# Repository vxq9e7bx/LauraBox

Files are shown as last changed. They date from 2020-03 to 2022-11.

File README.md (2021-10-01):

# LauraBox
A children's juke box controlled by RFID tags, based on an ESP32.

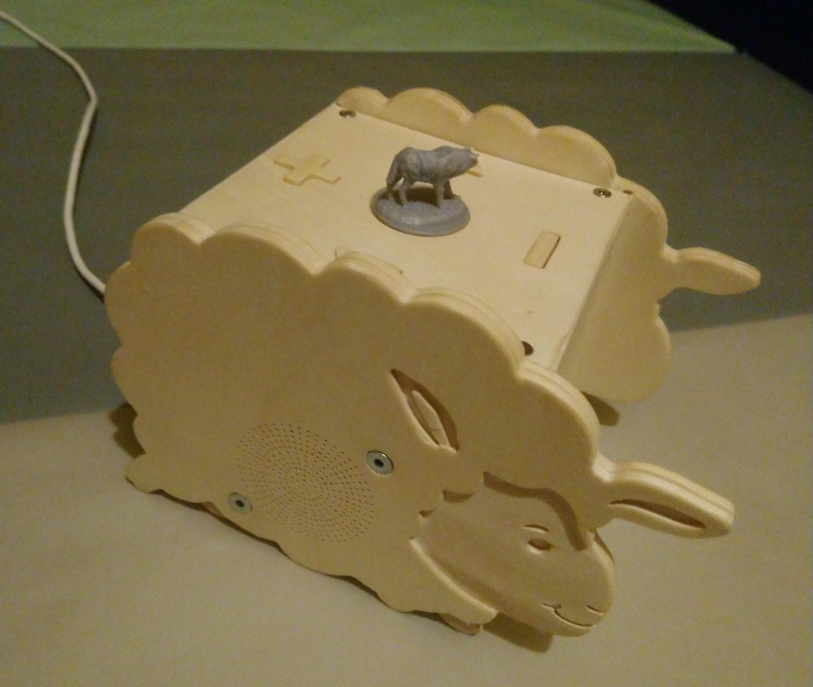
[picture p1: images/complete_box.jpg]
The ready box


## Features:
* Playback of user-defined MP3 playlists
* Playlist selected though RFID tag. Cheap RFID stickers can be placed on any 3D printed model.
* Battery powered, can play while charging
* Four buttons: volume +/-, next/previous track
* Intuitive pause functionality by removing the RFID tag and putting it back on to resume (no limit in pause time, no impact on battery life)
* WiFi download of new MP3s and playlists
* Firmware upgrade via WiFi
* Long standby time (several month)
* Long play time (many hours, if not days)
* Toddler proof :-)

## Main components
* EPS32 microcontroller
* MFRC522 RFID board
* PCM5102 I2S stereo audio DAC
* PAM8403 stereo amplifier
* Pair of wideband speakers
* 3.6V Li-ion battery with USB charge controller from a USB power bank (2x 18650-type cells with 2500 mAh)
* SD card to store MP3 files and playlists

## Why use the ESP32?

At first I was considering building the box based on a Raspberry Pi. I had an old first generation Pi lying around unused, so I though it would be a good way of using it. I was immediately disappointed by its sound quality. Although this is significantly better on newer models, I learned another lession: The power consumption of a Raspberry Pi is very high, and it takes a long time to boot. Keeping it always running to wait for an RFID card to be detected is out of the question, since I wanted it to run from battery. Adding a small microcontroller (I though of some ATMega) to switch on the Pi only when a card is detected would result in long wait times until the music starts playing. Also the power consumption while playing would be still quite high. A Raspberry Pi typically uses 300 to 500 mA, while an ESP32 just takes a few mA when WiFi is disabled. After short investigation I found the ESP32-audioI2S Arduino library. This makes playback of audio using an ESP32 super easy. Thanks to the ultra low power co-processor of the ESP32 it is possible to cut down the power consumption in sleep mode to around 0.5mA-1.0mA on average (incl. periodic wakeups and RFID reads), which gives you plenty of standby time on battery.

## Power supply

For power supply I have used an old USB power bank which I no longer needed. It has two 18650-typed cells with each 2500 mAh and a USB charge controller with an integrated boost converted to generate 5V from the ~3.6 V battery voltage (the cells are in parallel). The 5V USB voltage is not usable to power a very low power device, since the boost converter switches off if too little current is drawn. Since the electronics anyways runs on 3.3 V, the battery voltage is used without the boost converter directly. Since the voltage can be as high as 4 V or even higher when the battery is fully chaged, and the ESP32 has a maximum voltage of 3.6 V, a voltage regulator is required. I have decided for a MaxLinear XRP6272, since it has a very low quiescent current, a quite low dropout voltage and is able to provide a high enough current so that WiFi will work without problems.

The PCM5102 has unfortunately a relatively high quiescent current, hence I decided to use two XRP6272: one for the ESP32, the MRF522 and the SD card, the second formt the PCM5102. The first regulator is permanently enabled, since the ESP32 needs permanent power, and both the SD card and the MRF522 can be powered down to a sufficiently low quiescent current. Only the second regulator is controlled by software.

The PAM8403 is directly connected to the battery voltage, since it is favourable to power it with the highest possible voltage (up to 5V). I have experimented with using the 5V USB power as a supply, but it draws too little current to switch it on. Luckily, the power down mode of the PAM8403 is also sufficiently low, so no extra switch is required here.

It is a bit difficult to measure the power consumption in standby mode precisely, because it switches between deep-sleep modes and very short bursts of RFID-activity (with only the ULP processor working in the ESP32). The average current seems to be around 1mA. Since the battery cannot be used to its full capacity, because the voltage is getting too low at some point, the lifetime is a bit below the theoretical 5000hours = 208days. Even if it were only half of that, it would be still nothing to worry about too much.

Also to get down the power consumption, I have removed the LED from the MFRC522 board. It was always on even while the MFRC522 was put to standby and hence was unnecessarily drawing a significant amount of power.

## Firmware

The firmware is based on Arduino and uses the following libraries:
* ESP32 I2S audio library: https://github.com/schreibfaul1/ESP32-audioI2S
* ArduinoOTA (from Arduino library manager)
* ArduinoHttpClient (from Arduino library manager)

It also uses the ulptool (https://github.com/duff2013/ulptool) to program the ULP (ultra low power co-processor) of the ESP32.

Please have a look at the header of the Arduino sketch for instructions how to build the firmware. You will also have to create the `wifi-key.h` header file containing your WiFi credentials and the URL to download MP3 and playlists from (see section "Server setup for playlists and MP3 files"):
```
// Create wifi-key.h, put the following two definitions in and replace the **** with your WIFI credentials.
String ssid =     "****";
String password = "****";
String updateCard = <cardIdToActivateWifiUpload>;
String baseUrl = "http://url.to.download.new.card.content"
```

The `<cardIdToActivateWifiUpload>` is the RFID card id (as an integer, prefix with `0x` for hex format) which will trigger entering the WiFi firmware update and playlist/MP3 download mode.

### Usage of the ULP

The ULP periodically queries the status of the RFID card, wakes the main CPU if a new card is detected, and informs the main CPU of the current card ID and when the card is lost. Writing this code was the actual fun part of the firmware development for this project. The ULP is a very minimalistic CPU, there isn't even a (complete) C compiler (I wasn't able to get the experimental ULPCC compiler to work at all). So I had to write assembler code. There are only very few registers. The CPU doesn't even have a stack, but you can implement one (see `stack.s`). Since the ULP does not have access to the peripherals (they are powered down anyway), the SPI communication with the MRFC522 has to be bit-banged through normal GPIO pins. To get this right, I have basically observed the communication of a normal Arduino program using an MRFC522 library with a logic analyzer. Then I have basically coded the same sequence of bytes into the ULP program (see `init_sequence` section in `rtcio.s`). The only goal was to read the ID of the card, which is luckily not so hard to achieve. Even though some error checking is missing, the communication seems to be pretty reliably.

Since the ULP can also run when the main CPU is active, it will keep monitoring the presence of the RFID card and inform the main CPU when it is lost. The main CPU will then shutdown. An interesting fact about the ESP32 is also that the main CPU will be completely shutoff while in deep sleep mode, so when the ULP wakes it, it will boot the program from the very beginning (i.e. it will go through `setup()` again). Only by looking at the wakeup cause it is possible to distinguish this from a cold boot. All memory content (apart from the ULP accessible memory) will be lost, too. For this particular purpose this is perfectly fine, since the box does not need to store big amount of data while sleeping. Only the current volume setting and the last playback position is stored in the ULP memory.

## Electronics

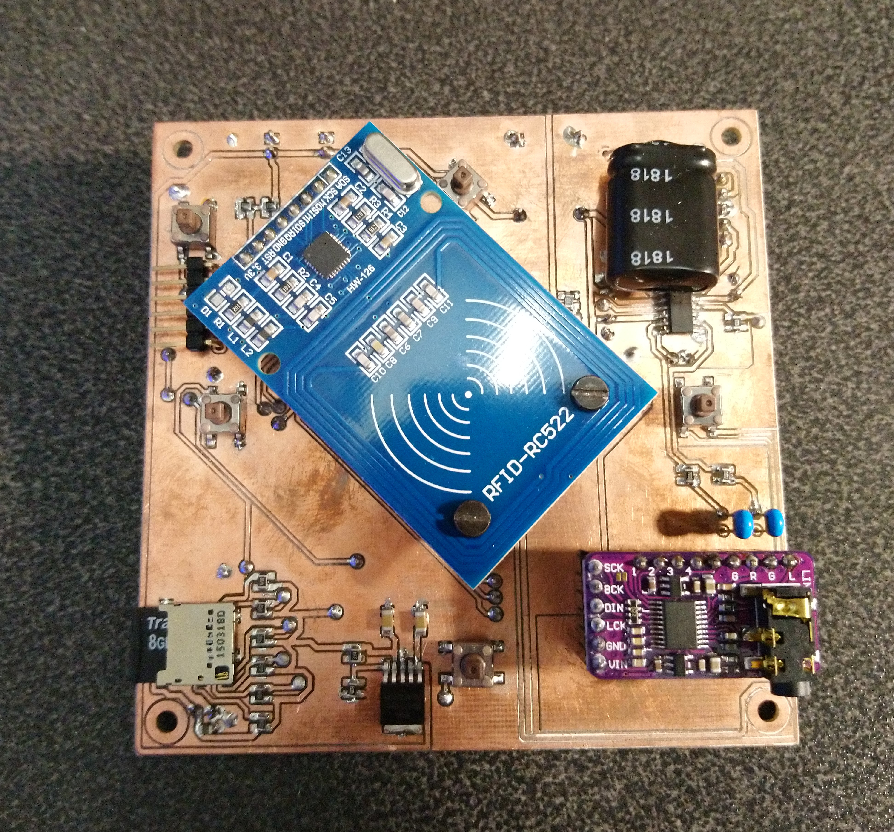
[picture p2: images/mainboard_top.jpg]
Mainboard top view

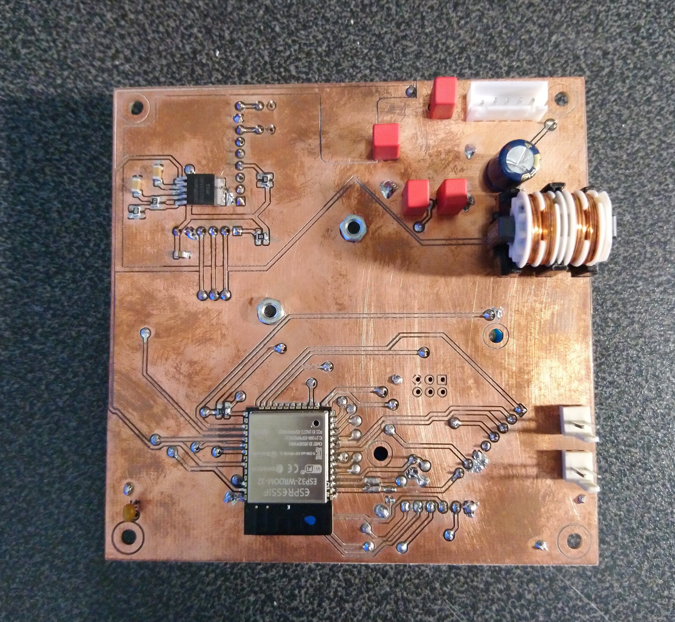
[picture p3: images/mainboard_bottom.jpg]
Mainboard bottom view


* Analogue part is well-separated from digital part, to avoid any influence of RFID or WiFi operation on sound quality.
* This works well, there is no audible noise from RFID or WiFi.

### Possible improvements:

* Some things may be a bit cheated: digital signals (I2S etc.) going to the analogue side should better be decoupled with opto-couplers, because ground levels might be different. It seems to work well like it is, though.
* Some components (choke, analogue supply bypass capacitor) are quite overdimensioned, just to be on the safe side.
  * I did that to avoid the risk of needing a second order with only a few parts, if I would estimate wrongly...
* Placement of some components was not smart:
  * The serial programming connector was originally planned as an upright connector, so it can be reached while the board is inside the box. This collided with the RFID board, so I changed it to an angled connector. This is a bit unhandy, because it requires taking the board out when using it. Also no big deal, since there is WiFi firmware upgarade...
  * Some bigger components, especially the choce, are placed a bit too close to the edge, which makes assembly a bit hard.
* Keep the area below the WiFi antenna free (no ground, no signals). This is hard to achieve with a home-produced board with just two layers, but at least one could move the signals as close as possible to the edge of the area and remove the ground plane there, ideally with a real cut out in the board.
* I am not an electronics engineer, surely one can do a number of other things better, too!

<p align="center">
Schematics
</p>

## Mechanical parts

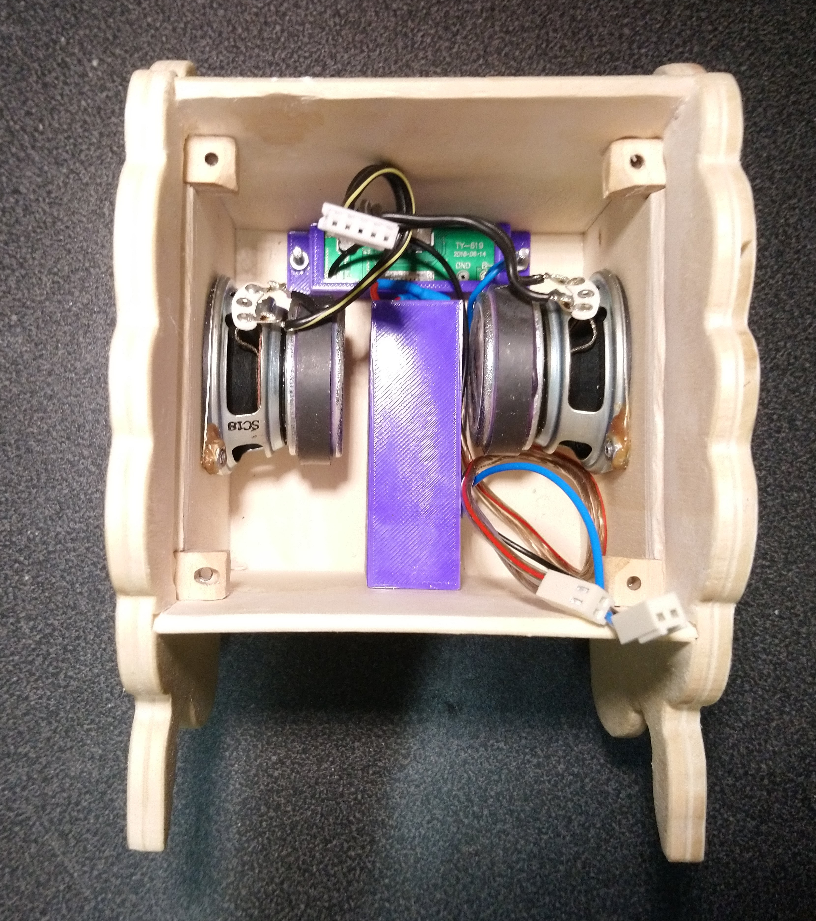
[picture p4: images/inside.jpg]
View inside opened box with mainboard removed


* The outer parts are made from plywood with a CNC mill.
  * Don't look to close at my work. This was the first time for me do build such a case with my CNC mill, which is more like a 3D printer that can also mill...
* The buttons are also made from wood, which creates a uniform look. The reset button can be triggered with a paper clip.
* The wood is finished with wood wax.
* The holder for the battery and the charge controller are 3D printed.
* The corners holding the electronics have nuts glued in from the bottom.
* Spacers are required between the electronics and the top lid of the casing.
* Speakers are secured with screws and nuts. To simplify the assembly, I have glued the nuts to the speakers.

### Possible improvements:

* The drilled holes for the sound to exit the box are too small, this degrades sound quality a bit unfortunately.
* Assembly is slightly tedious due to the spacers between electronics and the lid, but thanks to Wifi connectivity this needs not be done often.
* Also the box is a bit too small for the electronics board (or the board is to big). I had to grind some material off the walls on the inside to make it fit.

## Server setup for playlists and MP3 files

* A web server needs to be setup which provides playlists and MP3 files
* The web server needs to be reachable by the box when connected to the WiFi defined in `wifi-key.h` through the specified URI.
  * It is strongly recommended to restrict access to the web server to your local network or even just the IP address of the box, to avoid exposing copyrighted material to the internet.
* When detecting the special `updateCard`, the firmware will download a file called `0.lst.manifest`, which contains a list of file sizes and names (one entry per line).
* It will then check each entry whether the file exists on the SD card and its size matches. Any missing or wrong-sized file will be downloaded. Any extra file will be deleted.
* Playlists need to be named after the card ID which should activate the play back of the list: `<cardId>.lst` (e.g. `deadbeef.lst` if `deadbeef` is a card id). They simply contain a plain list of MP3 files which should be played back in sequence. The playlist file and all MP3s need to be in the manifest file, so they are properly downloaded.
* During playback, there normally is no WiFi connection to safe power. It is possible though to have web radio streams in the playlists. If a playlist entry starts with `http://`, WiFi will be activated before the stream is started. Note that this will work only with MP3-based streams, and it will reduce the battery life considerably.
* To generate a playlist on a Linux system, use the script `scripts/makeList.sh`.
* To generate or update the manifest, use the script `scripts/makeManifest.sh`.
* Do not use non-ASCII characters in file names. Use the script `scripts/fileRenamer.sh` to rename files such that those characters are avoided.
* To correct the sound distortions caused by the small holes in the casing letting, I use the script `scripts/soundCorrection.sh`. I would recommend rather making those holes bigger, but if you face similar issues this can be helpful.
* If you have a Youtube Music account and want to download MP3 files from there to the box, have a look at the scripts `scripts/ytmSetup.py` and `scripts/ytmLoader.py` and modify them for your needs.

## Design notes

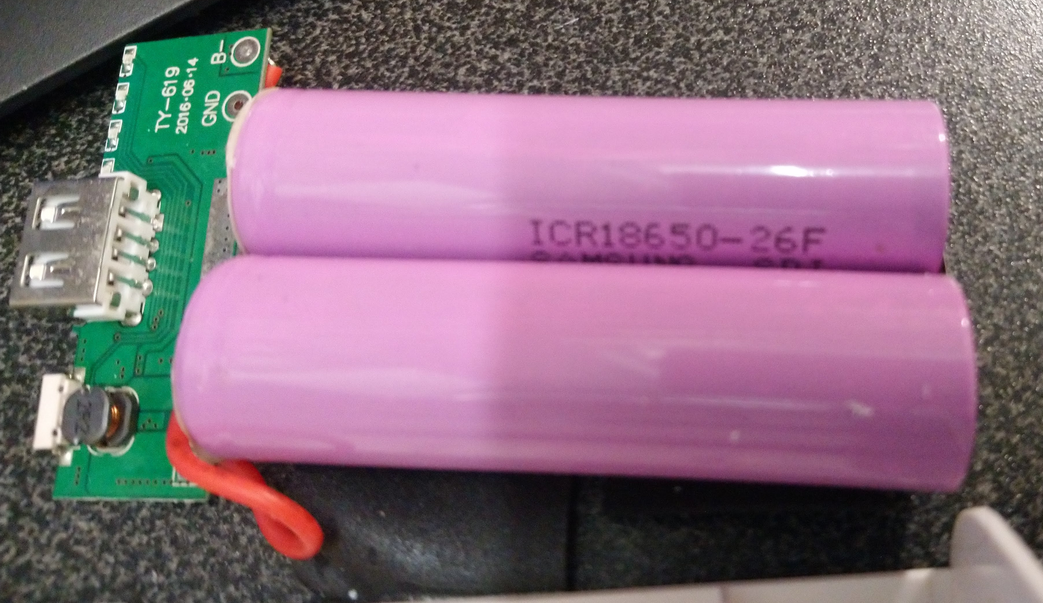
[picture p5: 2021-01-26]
images/battery.jpg

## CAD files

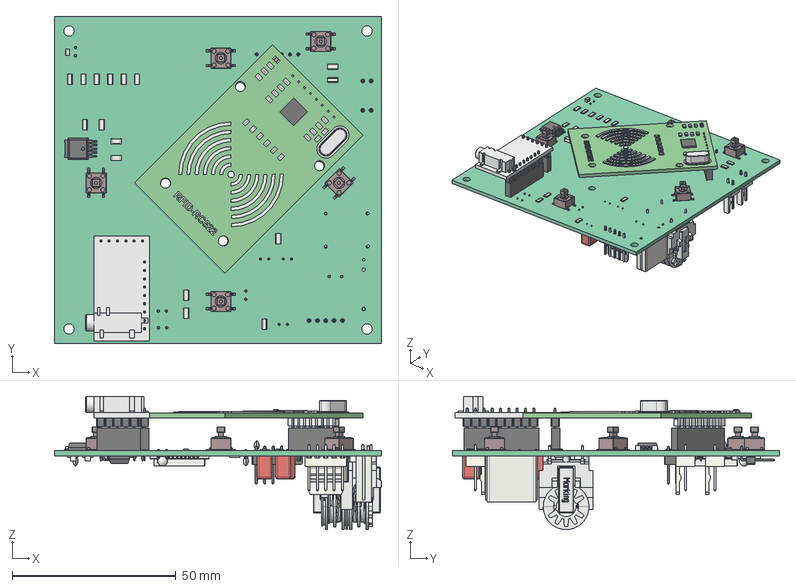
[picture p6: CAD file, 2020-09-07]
3D model/Hardware.FCStd
99.8 x 99.8 x 40.7 mm
Pcb_2b025
J2_PinSocket_1x08_P254mm_Vertical_5EEF61B008
U2_TO_252_5_TabPin3_5EDC5DDD001
SW5_Fusion005_5EE2871B001
SW4_Fusion005_5EDC5ACE001
SW3_Fusion005_5F4BBD069
SW2_Fusion005_5EDC586A001
SW1_Fusion005_5EDC5739
R20_R_0612_1632Metric_5EDC5607
R19_R_0612_1632Metric_5EDC557B001
R16_R_0612_1632Metric_5EDC53DA001
R15_R_0612_1632Metric_5EE28B7A001
R12_R_0612_1632Metric_5EDC51AE001
R10_R_0612_1632Metric_5EE2B378
R8_R_0612_1632Metric_5EDC4F083
R7_R_0612_1632Metric_5EE2B46F001
R6_R_0612_1632Metric_5EDC4E6C001
R5_R_0612_1632Metric_5EE2DAEE001
R4_R_0612_1632Metric_5EE2DA1B001
R3_R_0612_1632Metric_5EE3B1FA001
R2_R_0612_1632Metric_5EEF4EFE001
R1_R_0612_1632Metric_5EDC4BB006
J7_PinSocket_1x09_P254mm_Vertical_5EE2AF3B001
J6_PinSocket_1x06_P254mm_Vertical_5EE2AEBD001
C6_C_1206_3216Metric_5EDBC9E009
C4_C_1206_3216Metric_5EE2B2D003
C3_C_Disc_D30mm_W16mm_P250mm_5EE2B940
C1_C_0805_2012Metric_5F4EFC045
J4_PinHeader_1x06_P254mm_Horizontal_5EDC3D082
J9_Molex_AE_6410_02A_5F4B7D022
J1_Molex_AE_6410_02A_5F4B78A003
L1_Download_STP_WE-FC-UT20V_rev1 7448640415 _5EEDF6A010
U3_TO_252_5_TabPin3_5EEF7DB005
C9_C_Rect_L165mm_W47mm_P1500mm_MKT_5F4EFEB005
J8_Molex_AE_6410_05A_5F4ABA3E001
U1_ESP32-WROOM-32_5EEF473B001
R18_R_0612_1632Metric_5EE2AE025
R17_R_0612_1632Metric_5EE2AEFF001
R14_R_0612_1632Metric_5EE2AF084
R13_R_0612_1632Metric_5EEF6308
R11_R_0612_1632Metric_5EDC5124
R9_R_0612_1632Metric_5EEF653E001
J5_PinHeader_2x03_P254mm_Vertical_5EEF3D9B001
C17_C_1206_3216Metric_5EEF8248
C16_C_Disc_D30mm_W16mm_P250mm_5EEFAD5F001
C15_C_Disc_D30mm_W16mm_P250mm_5EE2F10F001
C14_C_Disc_D30mm_W16mm_P250mm_5EE2AAE003
C13_C_Rect_L46mm_W55mm_P250mm_MKS02_FKP02_5EE29621
C12_C_1206_3216Metric_5EEF7D036
C11_C_Rect_L46mm_W55mm_P250mm_MKS02_FKP02_5EE2A625
C10_C_Rect_L46mm_W55mm_P250mm_MKS02_FKP02_5EE2A70F001
C8_CP_Radial_D80mm_P380mm_5EE29863
C7_C_0805_2012Metric_5EE2AE055
C5_C_0805_2012Metric_5EEF6242
C2_C_Disc_D30mm_W16mm_P250mm_5EE2D7CE001
Komponente1
Komponente2
Pin Header 2,54 mm v4 (7)
Pin Header 2,54 mm v4 (6)
Pin Header 2,54 mm v4 (5)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

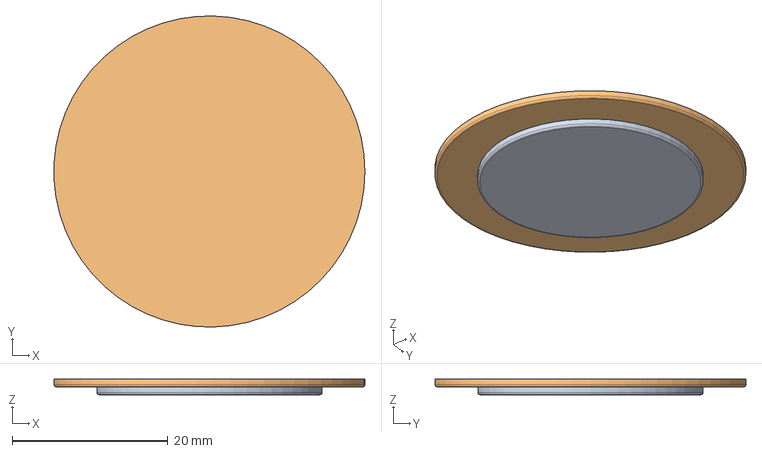
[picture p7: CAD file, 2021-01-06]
base plate/base plate 40mm.FCStd
40.0 x 40.0 x 2.00 mm

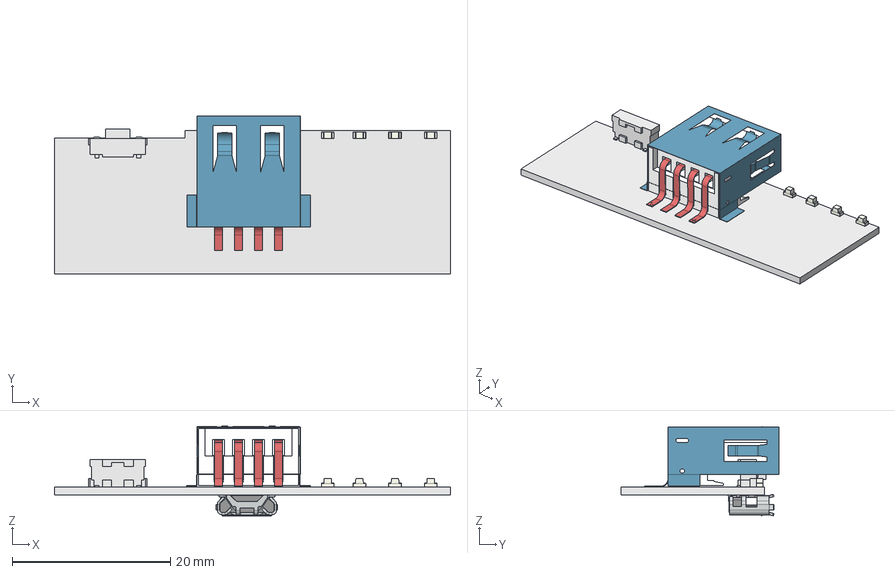
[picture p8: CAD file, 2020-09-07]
3D model/Charger.FCStd
50.0 x 20.0 x 11.3 mm
shield
socket_housing
socket_plate
terminal
terminal001
terminal002
terminal003
terminal004
1__Outside
3_Cable
2__Inside
4_Signs
Switch001
LED 1
LED 2
LED 3
LED 4

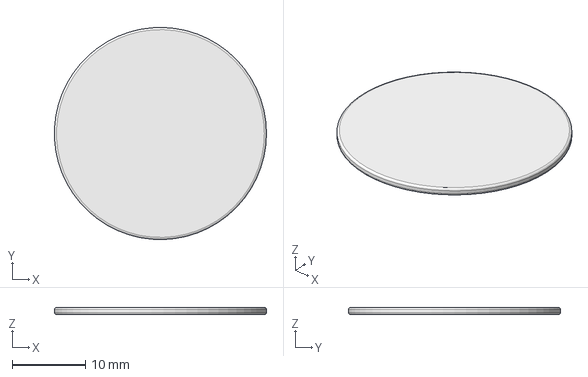
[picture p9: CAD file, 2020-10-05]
base plate/base plate.FCStd
29.0 x 29.0 x 1.00 mm

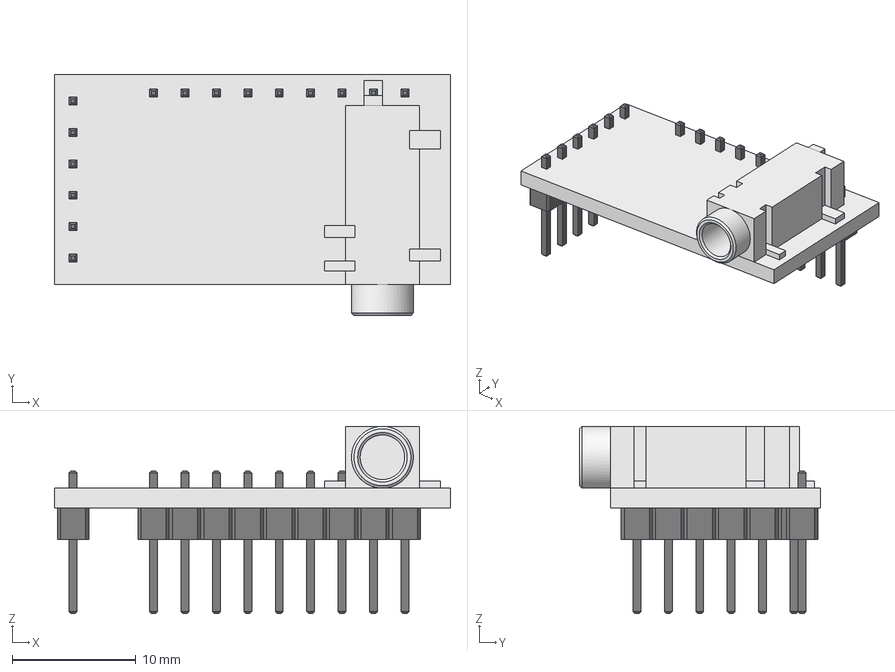
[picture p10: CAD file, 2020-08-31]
3D model/GY-PCM510x.FCStd
32.0 x 19.5 x 15.1 mm
PinHeader_1x06_P254mm_Vertical
PinHeader_1x09_P254mm_Vertical
Audio Jack slightly wrong type

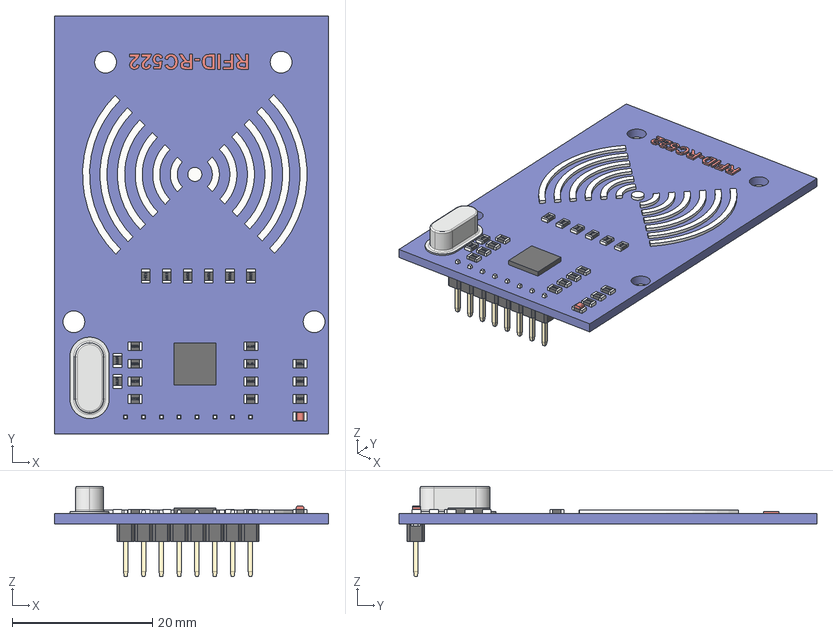
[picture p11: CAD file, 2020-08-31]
3D model/RC522 v8.step
39.1 x 59.6 x 12.9 mm
Komponente1
Komponente2
Pin Header 2,54 mm v4 (7)
Pin Header 2,54 mm v4 (6)
Pin Header 2,54 mm v4 (5)
Pin Header 2,54 mm v4 (4)
Pin Header 2,54 mm v4 (3)
Pin Header 2,54 mm v4 (2)
Pin Header 2,54 mm v4 (1)
Pin Header 2,54 mm v4
R-0805
Komponente1_1
R-0805 v4 x 20
RC522_1
NFC
Schrift

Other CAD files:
base plate/base-plate-40mm.stl
base plate/base-plate.stl

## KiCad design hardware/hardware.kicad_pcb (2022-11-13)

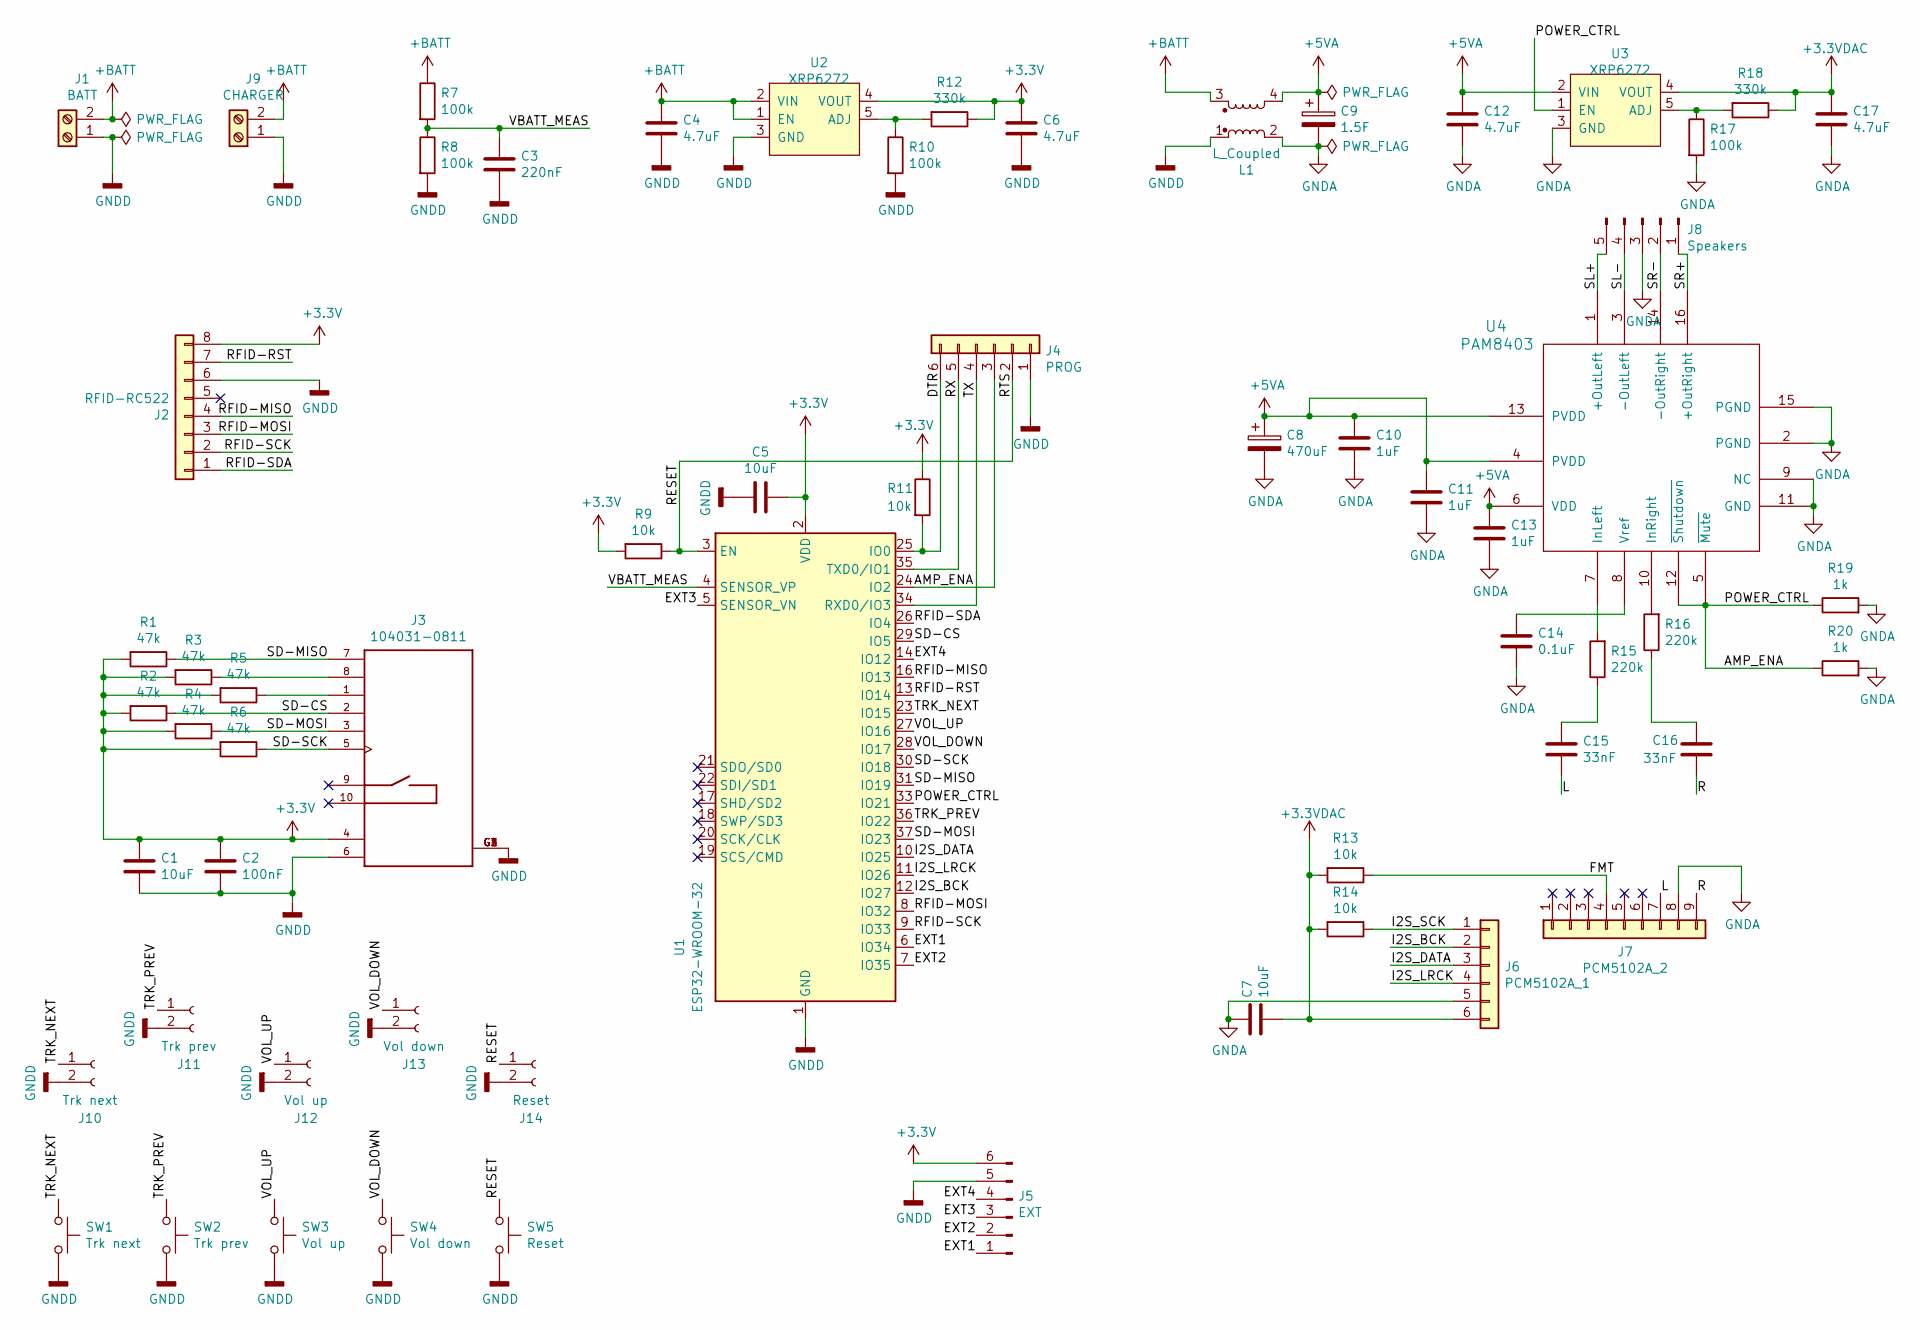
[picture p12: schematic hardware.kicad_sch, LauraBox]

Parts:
C1, C5, C7: 10uF; C_0805_2012Metric_Pad1.15x1.40mm_HandSolder
C2: 100nF; C_Disc_D3.0mm_W1.6mm_P2.50mm
C3: 220nF; C_Disc_D3.0mm_W1.6mm_P2.50mm
C4, C6, C12, C17: 4.7uF; C_1206_3216Metric_Pad1.42x1.75mm_HandSolder
C8: 470uF; CP_Radial_D8.0mm_P3.80mm
C9: 1.5F; C_Rect_L16.5mm_W8.7mm_P15.00mm_MKT
C10, C11, C13: 1uF; C_Rect_L4.6mm_W5.5mm_P2.50mm_MKS02_FKP02
C14: 0.1uF; C_Disc_D3.0mm_W1.6mm_P2.50mm
C15, C16: 33nF; C_Disc_D3.0mm_W1.6mm_P2.50mm
J1: BATT; Molex_KK-254_AE-6410-02A_1x02_P2.54mm_Vertical
J2: RFID-RC522; RFID-RC522-Module
J3: 104031-0811; 1040310811
J4: PROG; Molex_KK-254_AE-6410-06A_1x06_P2.54mm_Vertical
J5: EXT; PinHeader_2x03_P2.54mm_Vertical
J6: PCM5102A_1; PinSocket_1x06_P2.54mm_Vertical
J7: PCM5102A_2; PinSocket_1x09_P2.54mm_Vertical
J8: Speakers; Molex_KK-254_AE-6410-05A_1x05_P2.54mm_Vertical
J9: CHARGER; Molex_KK-254_AE-6410-02A_1x02_P2.54mm_Vertical
J10: Trk next; PinHeader_1x02_P2.54mm_Vertical
J11: Trk prev; PinHeader_1x02_P2.54mm_Vertical
J12: Vol up; PinHeader_1x02_P2.54mm_Vertical
J13: Vol down; PinHeader_1x02_P2.54mm_Vertical
J14: Reset; PinHeader_1x02_P2.54mm_Vertical
L1: L_Coupled; Choke_21x17mm
R1, R2, R3, R4, R5, R6: 47k; R_0612_1632Metric_Pad1.18x3.40mm_HandSolder
R7, R8, R10, R17: 100k; R_0612_1632Metric_Pad1.18x3.40mm_HandSolder
R9, R11, R13, R14: 10k; R_0612_1632Metric_Pad1.18x3.40mm_HandSolder
R12, R18: 330k; R_0612_1632Metric_Pad1.18x3.40mm_HandSolder
R15, R16: 220k; R_0612_1632Metric_Pad1.18x3.40mm_HandSolder
R19, R20: 1k; R_0612_1632Metric_Pad1.18x3.40mm_HandSolder
SW1: Trk next; SW_Push_1P1T_NO_6x6mm_H9.5mm
SW2: Trk prev; SW_Push_1P1T_NO_6x6mm_H9.5mm
SW3: Vol up; SW_Push_1P1T_NO_6x6mm_H9.5mm
SW4: Vol down; SW_Push_1P1T_NO_6x6mm_H9.5mm
SW5: Reset; SW_Push_1P1T_NO_6x6mm_H9.5mm
U1: ESP32-WROOM-32
U2, U3: XRP6272; TO-252-5_TabPin3
U4: PAM8403; SOP-16_4.55x10.3mm_P1.27mm

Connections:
+3.3VDAC: C7.2, C17.1, J6.6, R13.2, R14.2, R18.1, U3.4 (VOUT)
+3V3: C1.1, C2.1, C5.1, C6.1, J2.8, J3.4 (VDD), J5.6, R1.2, R2.2, R3.2, R4.2, R5.2, R6.2, R9.2, R11.1, R12.1, U1.2 (VDD), U2.4 (VOUT)
+5VA: C8.1, C9.1, C10.1, C11.1, C12.1, C13.1, L1.4, U3.2 (VIN), U4.4 (PVDD), U4.6 (VDD), U4.13 (PVDD)
+BATT: C4.1, J1.2, J9.2, L1.3, R7.1, U2.1 (EN), U2.2 (VIN)
/AMP_ENA: J4.3, R19.1, R20.1, U1.24 (IO2), U1.33 (IO21), U3.1 (EN), U4.5 (~Mute), U4.12 (~Shutdown)
/DTR: J4.6, R11.2, U1.25 (IO0)
/EXT1: J5.1, U1.6 (IO34)
/EXT2: J5.2, U1.7 (IO35)
/EXT3: J5.3, U1.5 (SENSOR_VN)
/EXT4: J5.4, U1.14 (IO12)
/FMT: J7.4, R13.1
/I2S_BCK: J6.2, U1.12 (IO27)
/I2S_DATA: J6.3, U1.10 (IO25)
/I2S_LRCK: J6.4, U1.11 (IO26)
/I2S_SCK: J6.1, R14.1
/L: C15.2, J7.7
/R: C16.1, J7.9
/RESET: J4.2, J14.1, R9.1, SW5.1, U1.3 (EN)
/RFID-MISO: J2.4, U1.16 (IO13)
/RFID-MOSI: J2.3, U1.8 (IO32)
/RFID-RST: J2.7, U1.13 (IO14)
/RFID-SCK: J2.2, U1.9 (IO33)
/RFID-SDA: J2.1, U1.26 (IO4)
/RX: J4.5, U1.35 (TXD0/IO1)
/SD-CS: J3.2 (CD/DAT3), R2.1, U1.29 (IO5)
/SD-MISO: J3.7 (DAT0), R1.1, U1.31 (IO19)
/SD-MOSI: J3.3 (CMD), R4.1, U1.37 (IO23)
/SD-SCK: J3.5 (CLK), R6.1, U1.30 (IO18)
/SL+: J8.5, U4.1 (+OutLeft)
/SL-: J8.4, U4.3 (-OutLeft)
/SR+: J8.1, U4.16 (+OutRight)
/SR-: J8.2, U4.14 (-OutRight)
/TRK_NEXT: J10.1, SW1.1, U1.23 (IO15)
/TRK_PREV: J11.1, SW2.1, U1.36 (IO22)
/TX: J4.4, U1.34 (RXD0/IO3)
/VBATT_MEAS: C3.1, R7.2, R8.1, U1.4 (SENSOR_VP)
/VOL_DOWN: J13.1, SW4.1, U1.28 (IO17)
/VOL_UP: J12.1, SW3.1, U1.27 (IO16)
GNDA: C7.1, C8.2, C9.2, C10.2, C11.2, C12.2, C13.2, C14.1, C17.2, J6.5, J7.8, J8.3, L1.2, R17.2, R19.2, R20.2, U3.3 (GND), U4.2 (PGND), U4.9 (NC), U4.11 (GND), U4.15 (PGND)
GNDD: C1.2, C2.2, C3.2, C4.2, C5.2, C6.2, J1.1, J2.6, J3.6 (VSS), J3.G1 (GND), J3.G2 (GND), J3.G3 (GND), J3.G4 (GND), J4.1, J5.5, J9.1, J10.2, J11.2, J12.2, J13.2, J14.2, L1.1, R8.2, R10.2, SW1.2, SW2.2, SW3.2, SW4.2, SW5.2, U1.1 (GND), U1.15 (GND), U1.38 (GND), U1.39 (GND), U2.3 (GND)
unnamed: C14.2, U4.8 (Vref)
unnamed: C15.1, R15.1
unnamed: C16.2, R16.1
unnamed: J3.1 (DAT2), R5.1
unnamed: J3.8 (DAT1), R3.1
unnamed: R10.1, R12.2, U2.5 (ADJ)
unnamed: R15.2, U4.7 (InLeft)
unnamed: R16.2, U4.10 (InRight)
unnamed: R17.1, R18.2, U3.5 (ADJ)

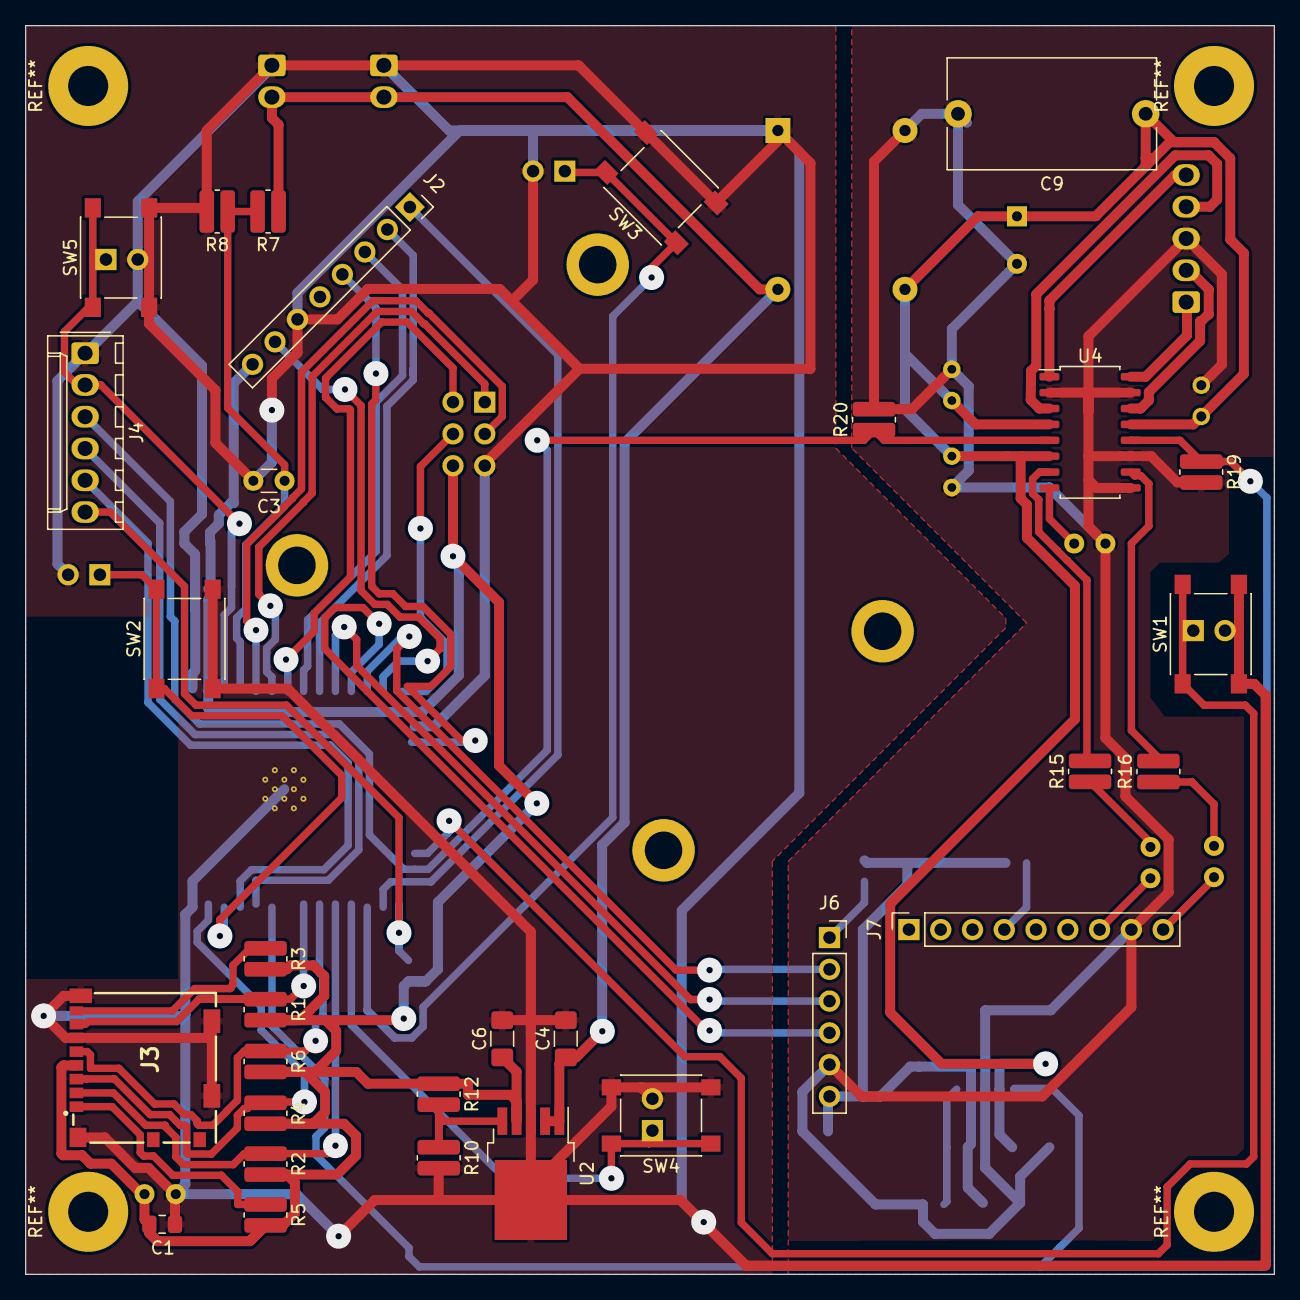
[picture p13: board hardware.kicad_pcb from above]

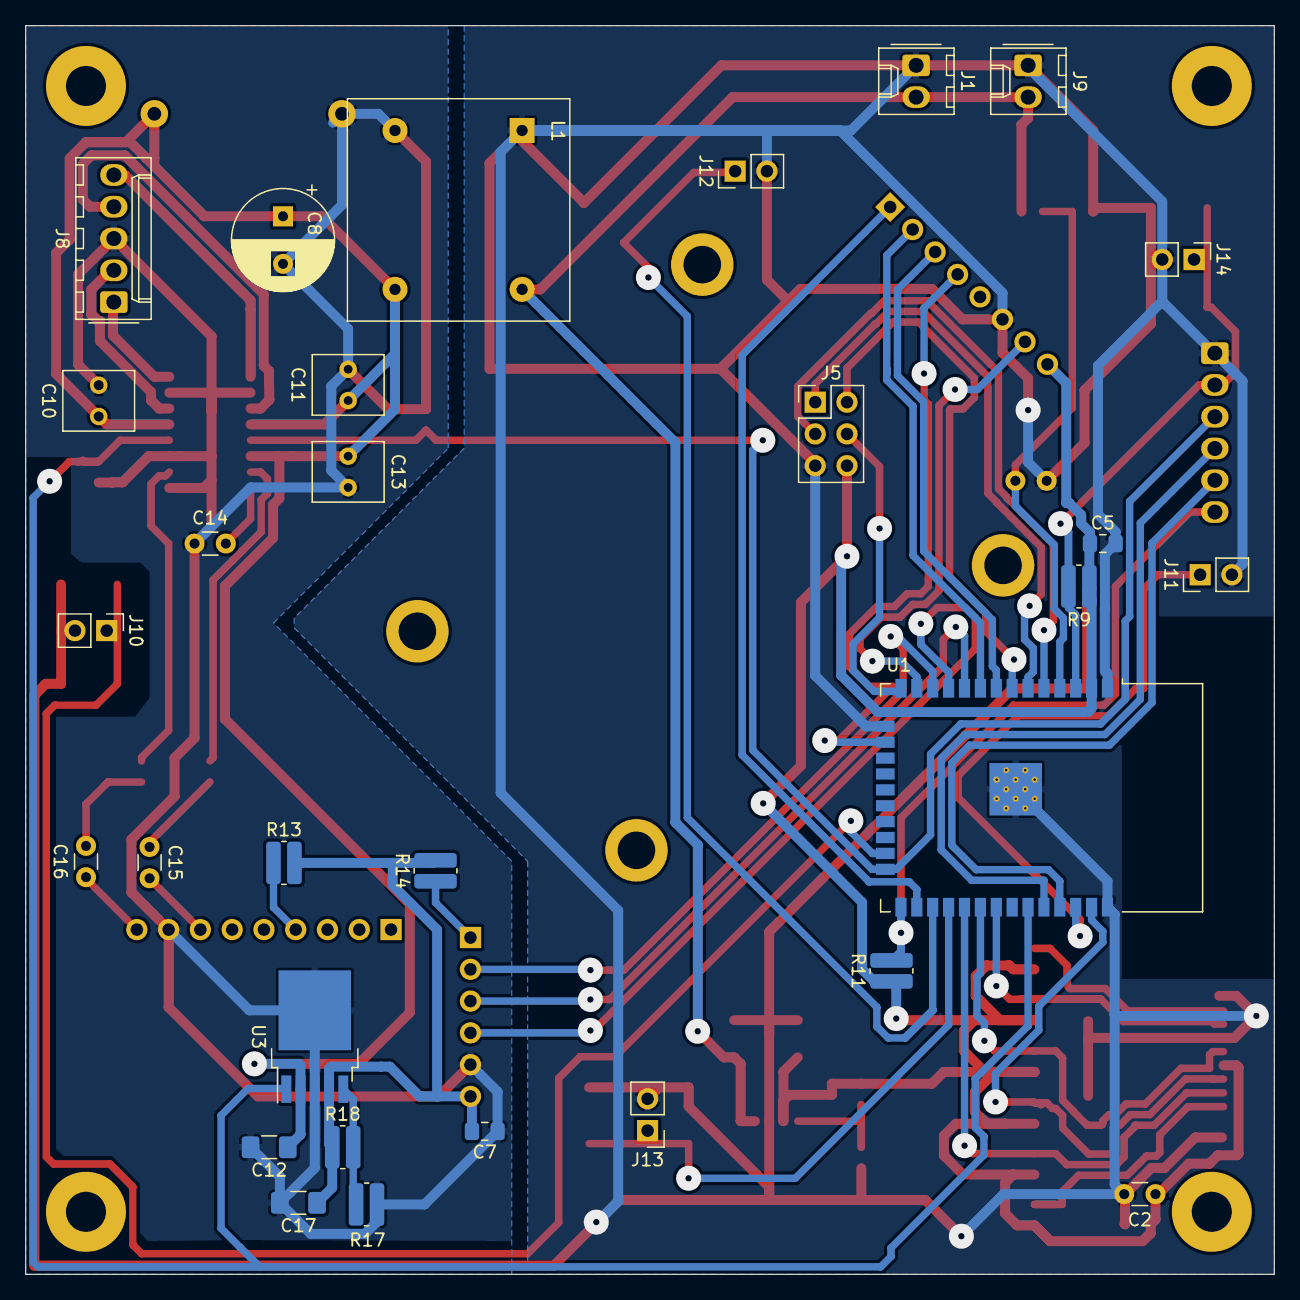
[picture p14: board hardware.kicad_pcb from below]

Board: 2 copper layers, 99.8 x 99.8 mm, 61 parts (30 on the bottom side), 49 nets.

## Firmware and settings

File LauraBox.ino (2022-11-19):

//
// Configure ESP32 Arduino support: https://github.com/espressif/arduino-esp32
//
// Change Board to "ESP32 Dev Module".
//
// Need to change this in ".arduino15/packages/esp32/hardware/esp32/1.0.4/tools/sdk/include/config/sdkconfig.h":
// #define CONFIG_ULP_COPROC_RESERVE_MEM 2048
//
// Need to install EPS32-audioI2S from here (download as ZIP, add via Sketch/Include Library)
// https://github.com/schreibfaul1/ESP32-audioI2S/
//
// Install ArduinoHttpClient library through Library Manager.
//
// Install the ulptool: https://github.com/duff2013/ulptool
// Note: On newer systems Python 2 might no longer work. Python 3 support is around the corner, see: https://github.com/duff2013/ulptool/pull/67
//

//#define TEST

#include <thread>
#include <atomic>
#include <set>
#include <vector>
#include <mutex>

#include "Arduino.h"
#include "WiFi.h"
#include "Audio.h"
#include "SD.h"
#include "FS.h"
#include <SPI.h>
#include "SPIFFS.h"

#include <WiFi.h>
#include <ESPmDNS.h>
#include <WiFiUdp.h>
#include <ArduinoOTA.h>
#include <WiFiClient.h>
#include <ArduinoHttpClient.h>

#include "esp_deep_sleep.h"
#include "nvs.h"
#include "nvs_flash.h"
#include "soc/rtc_cntl_reg.h"
#include "soc/rtc_io_reg.h"
#include "soc/sens_reg.h"
#include "soc/soc.h"
#include "driver/gpio.h"
#include "driver/rtc_io.h"
#include "esp32/ulp.h"
#include "ulp_main.h"
#include "ulptool.h"
#include "esp_task_wdt.h"

extern const uint8_t ulp_main_bin_start[] asm("_binary_ulp_main_bin_start");
extern const uint8_t ulp_main_bin_end[]   asm("_binary_ulp_main_bin_end");

// Create wifi-key.h, put the following two definitions in and replace the **** with your WIFI credentials.
//String ssid =     "****";
//String password = "****";
//String updateCard = <cardIdToActivateWifiUpload>;
//String baseUrl = "http://url.to.download.new.card.content"
// Note: <cardIdToActivateWifiUpload> must be an interger value. If you specify it as a hex code, prefix it with "0x".
#include "wifi-key.h"

#include "Button.h"

// Pins for RC522 - need to be accessible by RTC / ULP coprocessor
#define GPIO_NFC_SDA  GPIO_NUM_4    // GPIO 4, RTC GPIO 10
#define GPIO_NFC_RST  GPIO_NUM_14   // GPIO 14, RTC GPIO 16
#define GPIO_NFC_MOSI GPIO_NUM_32   // GPIO 32, RTC GPIO 9
#define GPIO_NFC_MISO GPIO_NUM_13   // GPIO 13, RTC GPIO 14
#define GPIO_NFC_SCK  GPIO_NUM_33   // GPIO 33, RTC GPIO 8

// Pins for SD card
#define SD_CS          5
#define SPI_MOSI      23
#define SPI_MISO      19
#define SPI_SCK       18

// Pins for I2S audio interface
#define I2S_DOUT      25
#define I2S_SCK       27
#define I2S_LRCK      26

// Pin for power control (DAC and amplifier)
#define POWER_CTRL    21

// Pin for amplifier /shutdown and /mute signals
#define AMP_ENA       2   // needs to be pulled low for fw download -> put to programmer connector to be safe

// ADC channel to read the battery voltage. Keep in sync with constant in rtcio.s
#define ADC_CH_VBATT ADC1_CHANNEL_0

// Define push buttons (with pin numbers)
Button volumeUp{15};
Button volumeDown{22};    // suppresses boot messages if low => acceptable side effect
Button trackNext{17};
Button trackPrev{16};

// Maximum allowed length of file names in playlist (to prevent buffer overflow in case of corrupted files)
const int maxPathLength = 512;

// Maximum number of minutes the cpu might run after waking up (to prevent battery drain if something is stuck)
const unsigned int runMaxMinutes = 120;

// Maximum allowed playback volume (cannot be bigger than 20)
const unsigned int maxVolume = 8;

std::recursive_mutex mx_audio;
Audio audio;
SPIClass sdspi(VSPI);

std::thread audioLoop;

std::mutex mx_playlist_and_track;
std::vector<String> playlist;
size_t track{0};

hw_timer_t *timer{nullptr};

uint32_t active_card_id{0};
std::atomic<bool> isStreaming{false};
std::atomic<bool> isMessage{false};

void IRAM_ATTR onTimer();

bool isUpdateMode{false};

std::atomic<size_t> wifiUseCount;
bool connectWifi(bool required=true);
void disconnectWifi();

String urlencode(String str);

// Buffer for downloading files
const int blockSize = 1024;
uint8_t buffer[blockSize];

unsigned long idleTime = 0;

/**************************************************************************************************************/

void runAudioLoop(void * parameter = nullptr) {
  delay(100);
  while(true) {
    {
      std::lock_guard<std::recursive_mutex> lk(mx_audio);
      audio.loop();
    }
    delay(1);
  }
}

/**************************************************************************************************************/

void setupOTA() {
  ArduinoOTA
    .onStart([]() {
      String type;
      if (ArduinoOTA.getCommand() == U_FLASH)
        type = "sketch";
      else // U_SPIFFS
        type = "filesystem";
  
  
      SPIFFS.end();
      Serial.println("Start updating " + type);
    })
    .onEnd([]() {
      Serial.println("\nEnd");
    })
    .onProgress([](unsigned int progress, unsigned int total) {
      Serial.printf("Progress: %u%%\r", (progress / (total / 100)));
    })
    .onError([](ota_error_t error) {
      Serial.printf("Error[%u]: ", error);
      if (error == OTA_AUTH_ERROR) Serial.println("Auth Failed");
      else if (error == OTA_BEGIN_ERROR) Serial.println("Begin Failed");
      else if (error == OTA_CONNECT_ERROR) Serial.println("Connect Failed");
      else if (error == OTA_RECEIVE_ERROR) Serial.println("Receive Failed");
      else if (error == OTA_END_ERROR) Serial.println("End Failed");
    })
    .setHostname("LauraBox")
    .setPort(3232);

    connectWifi();
    isUpdateMode = true;
    ArduinoOTA.begin();
    Serial.println("Update mode enabled.");
    voiceMessage("OTA");
}

/**************************************************************************************************************/

void updatePlaylists(void * parameter = nullptr) {
    // flag whether the file downloaded is the first or not, allows to produce different voice messages
    bool firstFile = true;
  
    // connect wifi
    if(!connectWifi(false)) {
      Serial.printf("Could not connect to wifi!\n");
      voiceMessage("error");
      vTaskDelete(NULL);
    }

    String id = String(active_card_id, HEX);
    WiFiClient c;
    HttpClient httpManifest(c, serverAddress, 80);
  
    // download playlist
    auto url = "/"+id+".lst.manifest";
    Serial.println("Attempting url: "+url);
  
    httpManifest.get(url);
    int httpCode = httpManifest.responseStatusCode();
    if(httpCode < 200 || httpCode > 299) {
      Serial.print("Http error: ");
      Serial.println(httpCode);
      voiceMessage("error");
      vTaskDelete(NULL);
    }
    Serial.println("Found online, starting download...");
    auto body = httpManifest.responseBody();
    if(body == "NOT FOUND\n") {
      Serial.println("Not found!");
      voiceMessage("error");
      vTaskDelete(NULL);
    }
    httpManifest.stop();
  
    // split body into list
    char* copy = strdup(body.c_str());
    char *ctrack = strtok(copy, "\n");
    std::vector<String> newlist;
    std::vector<size_t> newlist_sizes;
    while(ctrack != nullptr) {
      String track;
      size_t tracksize;
      for(char *ctrackname = ctrack; *ctrackname != '\0'; ++ctrackname) {
        if(*ctrackname == ' ') {
          track = String(ctrackname+1);
          ctrackname = '\0';
          tracksize = atoi(ctrack);
          break;
        }
      }
      if(track[track.length()-1] == '\r') track = track.substring(0, track.length()-1);
      if(track.length() > maxPathLength) continue;
      newlist.push_back(track);
      newlist_sizes.push_back(tracksize);
      ctrack = strtok(nullptr, "\n");
    }
    free(copy);

    Serial.println("NEWLIST BEGIN");
    for(size_t i=0; i<newlist.size(); ++i) {
      Serial.print(newlist[i]+": ");
      Serial.println(newlist_sizes[i]);
    }
    Serial.println("NEWLIST END");

    // check if playlist already exists (and is not empty)
    bool listWasPresentBefore = false;
    if(SD.exists("/" + id + ".lst")) {
      auto f = SD.open("/" + id + ".lst", FILE_READ);
      if(f.size() > 3) listWasPresentBefore = true;
      f.close();
    }

    // if playlist file does not yet exist, write it out now, so the playback can begin as soon as the first track is there
    if(!listWasPresentBefore) {
      auto f = SD.open("/" + id + ".lst", FILE_WRITE);
      for(auto &track : newlist) {
        f.println(track);
      }
      f.close();
      Serial.println("playlist stored");
    }    
    
    // download each track on playlist, if file size does not match or not yet existing
    bool playlistChanged = false;
    for(size_t i=0; i<newlist.size(); ++i) {
      auto track = newlist[i];
      auto tracksize = newlist_sizes[i];
      bool download = false;
      if(SD.exists("/"+track)) {
        auto f = SD.open("/"+track, FILE_READ);
        if(f.size() != tracksize) {
          download = true;
        }
        f.close();
      }
      else {
        download = true;
      }

      if(download) {
        // Play message
        if(firstFile) {
          firstFile = false;
          voiceMessage("download");
        }
        else {
          voiceMessage("download_progress");
        }
        
        // Start download of the track file
        HttpClient httpTrack(c, serverAddress, 80);
        httpTrack.get(urlencode("/"+track));
        int httpCode = httpTrack.responseStatusCode();
        if(httpCode >= 200 && httpCode <= 299) {
          httpTrack.skipResponseHeaders();
          auto bodyLen = httpTrack.contentLength();
        
          Serial.println("Downloading '"+track+"'...");
          playlistChanged = true;
          
          // Create directories
          for(int i=0; i<track.length(); ++i) {
            if(track[i] == '/') {
              SD.mkdir('/'+track.substring(0,i));
            }
          }
          
          // Save file
          auto f = SD.open("/"+track, FILE_WRITE);
          for(auto i=0; i<bodyLen; i += blockSize) {

            // print progress to serial
            if(i%(blockSize*100) == 0) {
              delay(1); // prevent idle task to never run and trigger the watchdog...
              Serial.print(i/1024);
              Serial.print("/");
              Serial.print(bodyLen/1024);
              Serial.println(" kiB");
            }

            // wait until enough data is available
            int nBytesToRead = min(bodyLen - i, blockSize);
            int itocount = 0;
            while(httpTrack.available() < nBytesToRead) {
              delay(100);
              if(!httpTrack.connected() || ++itocount > 300) {
                Serial.print("Error downloading '"+track+"': timeout.");
                voiceMessage("error");
                vTaskDelete(NULL);
              }
            }

            // read from http stream
            httpTrack.read(buffer, nBytesToRead);

            // write to SD card
            f.write(buffer, nBytesToRead);
          }
          f.close();
          httpTrack.stop();
        }
        else {
          Serial.print("Error downloading '"+track+"': ");
          Serial.println(httpCode);
          voiceMessage("error");
          vTaskDelete(NULL);
        }
      }

      // abort if battery low
#ifndef TEST
      if(ulp_vbatt_low & 0xFFFF) {
        disconnectWifi();
        vTaskDelete(NULL);
      }
#endif
    }

    delay(1); // prevent idle task to never run and trigger the watchdog...
    
    // read previous playlist if it exists to check for differences
    if(listWasPresentBefore) {
      // read old list to memory
      std::vector<String> oldlist;
      auto f = SD.open("/" + id + ".lst", FILE_READ);
      while(f.available()) {
        String track = f.readStringUntil('\n');
        if(track[track.length()-1] == '\r') track = track.substring(0, track.length()-1);
        oldlist.push_back(track);
      }
      f.close();

      // compare number of tracks
      if(oldlist.size() != newlist.size()) playlistChanged = true;

      if(playlistChanged) {

        // update track list file
        auto f = SD.open("/" + id + ".lst", FILE_WRITE);
        for(auto &track : newlist) {
          f.println(track);
        }
        f.close();

        delay(1); // prevent idle task to never run and trigger the watchdog...

        // search for orphaned tracks
        Serial.println("Checking for orphaned tracks...");
        // remove each track from oldlist which is present in the newlist
        for(auto &track : oldlist) {
          bool found = false;
          for(auto &newtrack : newlist) {
            if(newtrack == track) {
              found = true;
              break;
            }
          }
          if(found) continue;
          Serial.println("Removing: "+track);
          SD.remove("/"+track);
        }
      }
    }

    delay(1); // prevent idle task to never run and trigger the watchdog...

    Serial.println("Playlist update complete!");

    voiceMessage("download_finished");
    vTaskDelete(NULL);
}

/**************************************************************************************************************/

void powerOff() {
  Serial.printf("Entering deep sleep\n\n");

  // shutdown SD card
  sdspi.end();
  digitalWrite(SD_CS, HIGH);
  sdspi.begin(SPI_SCK, SPI_MISO, SPI_MOSI);
  SD.begin(SD_CS);
  
  // inform ULP we are going to sleep
  ulp_main_cpu_sleeps = 1;
  // enable wakeup by ULP
  ESP_ERROR_CHECK( esp_sleep_enable_ulp_wakeup() );
  Serial.flush();
  esp_deep_sleep_start();
  // this never returns, the ESP32 is reset after deep sleep, hence setup() is called after wakeup
}

/**************************************************************************************************************/

static void init_ulp_program(bool firstBoot) {
  esp_err_t err;
  if(firstBoot) {
    /* Load ULP binary */
    err = ulptool_load_binary(0, ulp_main_bin_start, (ulp_main_bin_end - ulp_main_bin_start) / sizeof(uint32_t));
    ESP_ERROR_CHECK(err);

    /* Set ULP wake up period to 2 seconds */
    ulp_set_wakeup_period(0, 2 * 1000 * 1000);

    /* Slow alternative ULP wake up period in case of low battery: 10 minutes */
    ulp_set_wakeup_period(1, 60 * 1000 * 1000);  // * 10
  
    /* Start the ULP program */
    ESP_ERROR_CHECK( ulp_run((&ulp_entry - RTC_SLOW_MEM) / sizeof(uint32_t)));

    /* Set default volume */
    ulp_current_volume = 4;

    /* Clear last card id */
    ulp_last_card_id = 0;
  }

  adc1_config_channel_atten(ADC_CH_VBATT, ADC_ATTEN_DB_11);
  adc1_config_width(ADC_WIDTH_BIT_12);
  adc1_ulp_enable();

  err = rtc_gpio_init(GPIO_NFC_SDA);
  if (err != ESP_OK) Serial.printf("GPIO_NFC_SDA not ok for RTC\n");
  rtc_gpio_set_direction(GPIO_NFC_SDA, RTC_GPIO_MODE_OUTPUT_ONLY);

  err = rtc_gpio_init(GPIO_NFC_RST);
  if (err != ESP_OK) Serial.printf("GPIO_NFC_RST not ok for RTC\n");
  rtc_gpio_set_direction(GPIO_NFC_RST, RTC_GPIO_MODE_OUTPUT_ONLY);

  err = rtc_gpio_init(GPIO_NFC_MOSI);
  if (err != ESP_OK) Serial.printf("GPIO_NFC_MOSI not ok for RTC\n");
  rtc_gpio_set_direction(GPIO_NFC_MOSI, RTC_GPIO_MODE_OUTPUT_ONLY);

  err = rtc_gpio_init(GPIO_NFC_MISO);
  if (err != ESP_OK) Serial.printf("GPIO_NFC_MISO not ok for RTC\n");
  rtc_gpio_set_direction(GPIO_NFC_MISO, RTC_GPIO_MODE_INPUT_ONLY);

  err = rtc_gpio_init(GPIO_NFC_SCK);
  if (err != ESP_OK) Serial.printf("GPIO_NFC_SCK not ok for RTC\n");
  rtc_gpio_set_direction(GPIO_NFC_SCK, RTC_GPIO_MODE_OUTPUT_ONLY);

}

/**************************************************************************************************************/

uint32_t readCardIdFromULP() {
  uint32_t id;

  // spin lock
  while(true) {
    ulp_active_card_mutex_by_main_cpu = 1;
    if(! (ulp_active_card_mutex_by_ulp_cpu & 0xFFFF)) break;
    ulp_active_card_mutex_by_main_cpu = 0;
  }
  
  id = ((ulp_active_card_id_hi & 0xFFFF) << 16) | (ulp_active_card_id_lo & 0xFFFF);

  // release lock
  ulp_active_card_mutex_by_main_cpu = 0;

  return id;
}

/**************************************************************************************************************/

void clearSD() {
  Serial.println("Resetting SD card...");
  byte sd = 0;
  digitalWrite(SD_CS, LOW);
  size_t nRetry = 0;
  while(sd != 255) {
    sd = sdspi.transfer(255);
    delay(10);
    if(++nRetry > 100) {
      Serial.println("Giving up!");
      break;
    }
  }
  delay(10);
  digitalWrite(SD_CS, HIGH);
}

/**************************************************************************************************************/

void setup() {
  wifiUseCount = 0;
  
  Serial.begin(115200);

  // configure power control pin
  Serial.printf("Power on SD+Audio\n");
  pinMode(POWER_CTRL, OUTPUT);
  pinMode(AMP_ENA, OUTPUT);
  digitalWrite(AMP_ENA, LOW);
  digitalWrite(POWER_CTRL, HIGH);

  // Configure audo interface
  Serial.printf("Setup audio\n");
  audio.setPinout(I2S_SCK, I2S_LRCK, I2S_DOUT);

  // create task for audio loop (on a dedicated core)
  std::lock_guard<std::recursive_mutex> lk(mx_audio);   // prevent audio loop until setup is complete
  xTaskCreatePinnedToCore(runAudioLoop, "runAudioLoop", 10000, NULL, 3, NULL, 0);
  xTaskCreatePinnedToCore(limitRuntime, "limitRuntime",  2000, NULL, 4, NULL, 1);

  // Setup SD card (done always to make sure SD card is in sleep mode after reset)
  Serial.printf("Setup SD\n");
  pinMode(SD_CS, OUTPUT);
  size_t nRetrySD=0;
retry_sd:
  digitalWrite(SD_CS, HIGH);
  sdspi.begin(SPI_SCK, SPI_MISO, SPI_MOSI);
  if(!SD.begin(SD_CS)) {
    clearSD();
    sdspi.end();
    if(++nRetrySD < 10) goto retry_sd;
    voiceError("error");
  }

  // Check wake cause
  esp_sleep_wakeup_cause_t cause = esp_sleep_get_wakeup_cause();
  if (cause != ESP_SLEEP_WAKEUP_ULP) {
    Serial.printf("Cold start.\n");
    init_ulp_program(true);
#ifndef TEST
    powerOff();
#endif
  }
  Serial.printf("ULP wakeup.\n");
  Serial.print("VBATT: ");
  Serial.println(ulp_vbatt & 0xFFFF);

  // inform ULP we are awake
  ulp_main_cpu_sleeps = 0;

  // init ULP pins
  init_ulp_program(false);

  // set audio volume
  audio.setVolume(ulp_current_volume); // 0...21
  Serial.print("Volume: ");
  Serial.println(ulp_current_volume);

  // Setup timer for scanning the input buttons
  Serial.printf("Setup input timer\n");
  timer = timerBegin(0, 80, true);      // prescaler 1/80 -> count microseconds
  timerAttachInterrupt(timer, &onTimer, true);
  timerAlarmWrite(timer, 10000, true);  // alarm every 10000 microseconds -> 100 Hz
  timerAlarmEnable(timer);

  // Setup input pins for push buttons
  Serial.printf("Setup input buttons\n");
  for (auto b : buttonList) b->setup();

  Serial.printf("Enable amplifier\n");
  delay(500);
  digitalWrite(AMP_ENA, HIGH);

  // create task for main loop - we do not use the arduino loop(), because it makes problems if too much time is spent inside.
  xTaskCreatePinnedToCore(runMainLoop, "runMainLoop",  10000, NULL, 0, NULL, 1);

  Serial.printf("Init complete.\n");
}

/**************************************************************************************************************/

void voiceError(String file) {
  voiceMessage(file);
  powerOff();
}

/**************************************************************************************************************/

void voiceMessage(String file) {
  Serial.println("Message: "+file);
  isMessage = true;

  digitalWrite(AMP_ENA, HIGH);

  if(!SPIFFS.begin()){
    Serial.println("SPIFFS Mount Failed");
    powerOff();
  }

  {
    std::lock_guard<std::recursive_mutex> lk(mx_audio);
    audio.stopSong();
  }
  while(audio.isRunning()) delay(1);

  {
    std::lock_guard<std::recursive_mutex> lk(mx_audio);
    audio.setVolume(2);
    audio.connecttoFS(SPIFFS, file+".mp3");
  }
  while(audio.isRunning()) delay(1);
}

/**************************************************************************************************************/

void IRAM_ATTR onTimer() {
  for(auto b : buttonList) b->onTimer();
}

/**************************************************************************************************************/

bool connectWifi(bool required) {
  if(wifiUseCount++ == 0) {
    Serial.println("Connecting WIFI...");
    WiFi.mode(WIFI_STA);
    WiFi.begin(ssid.c_str(), password.c_str());
  }
  Serial.print("Waiting for WIFI...");
  size_t cTimeOut = 0;
  while(WiFi.status() != WL_CONNECTED) {
    if(++cTimeOut > 60) {
      if(!required) return false;
      voiceError("error");
    }
    delay(500);
  }
  Serial.print("IP address: ");
  Serial.println(WiFi.localIP());
  return true;
}

/**************************************************************************************************************/

void disconnectWifi() {
  if(--wifiUseCount == 0) {
    Serial.println("Disconnecting WIFI...");
    WiFi.disconnect();
    WiFi.mode(WIFI_OFF);
  }
}

/**************************************************************************************************************/

void play() {
  String uri;
  size_t theTrack;
  {
    std::unique_lock<std::mutex> lk(mx_playlist_and_track);
    if(track > playlist.size()-1) {
      Serial.println("Current track exceeds length of playlist.");
      lk.unlock();
      voiceError("error");
    }
    uri = playlist[track];
    theTrack = track;
  }

  
  Serial.println("Play: "+uri);
  
  if(!uri.startsWith("http://") && !uri.startsWith("https://")) {
    if(isStreaming) disconnectWifi();
    if(!SD.exists("/"+uri)) {
      voiceError("error");
    }
    std::lock_guard<std::recursive_mutex> lk(mx_audio);
    isStreaming = false;
    audio.connecttoSD(uri);
  }
  else {
    if(!isStreaming) connectWifi();
    std::lock_guard<std::recursive_mutex> lk(mx_audio);
    isStreaming = true;
    audio.connecttohost(uri);
  }
}

/**************************************************************************************************************/
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
void loop() {
  delay(100);
}

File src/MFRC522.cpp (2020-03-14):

/**************************************************************************/
/*!

  @file    MFRC522.cpp
  @author  Bjarte Johansen
  @licence ljos.mit-license.org

  SPI Driver for MFRC522 NFC/13.56 RFID Transceiver.

  Based on code by Dr.Leong ( WWW.B2CQSHOP.COM ) and
  Miguel Balboa (https://github.com/miguelbalboa/rfid).

 */
/**************************************************************************/

#include <Arduino.h>
#include "MFRC522.h"

/**************************************************************************/
/*!

  @brief Instantiates a new MFRC522 class.

  @param sad    SPI chip select pin (CS/SS/SSEL)
  @param reset  Not reset and power-down pin.

 */
/**************************************************************************/
MFRC522::MFRC522(int iface, int sck, int miso, int mosi, int sad, int reset)
: spi(iface)
{
  spi.begin(sck, miso, mosi, sad);

  _sad = sad;
  pinMode(_sad, OUTPUT);       // Set digital as OUTPUT to connect it to the RFID /ENABLE pin
  digitalWrite(_sad, HIGH);

  _reset = reset;
  pinMode(_reset, OUTPUT);       // Set digital pin, Not Reset and Power-Down
  digitalWrite(_reset, HIGH);

}

/**************************************************************************/
/*!

  @brief   Writes value to a register.

  @param   addr  The address a register.
  @param   val   The value to write to a register.

 */
/**************************************************************************/
void MFRC522::writeToRegister(byte addr, byte val) {
  digitalWrite(_sad, LOW);

  //Address format: 0XXXXXX0
  spi.transfer((addr<<1)&0x7E);
  spi.transfer(val);

  digitalWrite(_sad, HIGH);
}

/**************************************************************************/
/*!

  @brief   Reads the value at a register.

  @param   addr  The address a register.

  @returns The byte at the register.

 */
/**************************************************************************/
byte MFRC522::readFromRegister(byte addr) {
  byte val;
  digitalWrite(_sad, LOW);
  spi.transfer(((addr<<1)&0x7E) | 0x80);
  val =spi.transfer(0x00);
  digitalWrite(_sad, HIGH);
  return val;
}

/**************************************************************************/
/*!

  @brief   Adds a bitmask to a register.

  @param   addr   The address a register.
  @param   mask  The mask to update the register with.

 */
/**************************************************************************/
void MFRC522::setBitMask(byte addr, byte mask) {
  byte current;
  current = readFromRegister(addr);
  writeToRegister(addr, current | mask);
}

/**************************************************************************/
/*!

  @brief   Removes a bitmask from the register.

  @param   reg   The address a register.
  @param   mask  The mask to update the register with.

 */
/**************************************************************************/
void MFRC522::clearBitMask(byte addr, byte mask) {
  byte current;
  current = readFromRegister(addr);
  writeToRegister(addr, current & (~mask));
}

/**************************************************************************/
/*!

  @brief   Does the setup for the MFRC522.

 */
/**************************************************************************/
void MFRC522::begin() {
  digitalWrite(_sad, HIGH);

  reset();

  //Timer: TPrescaler*TreloadVal/6.78MHz = 24ms
  writeToRegister(TModeReg, 0x8D);       // Tauto=1; f(Timer) = 6.78MHz/TPreScaler
  writeToRegister(TPrescalerReg, 0x3E);  // TModeReg[3..0] + TPrescalerReg
  writeToRegister(TReloadRegL, 30);
  writeToRegister(TReloadRegH, 0);

  writeToRegister(TxAutoReg, 0x40);      // 100%ASK
  writeToRegister(ModeReg, 0x3D);        // CRC initial value 0x6363

  setBitMask(TxControlReg, 0x03);        // Turn antenna on.
}

/**************************************************************************/
/*!

  @brief   Sends a SOFTRESET command to the MFRC522 chip.

 */
/**************************************************************************/
void MFRC522::reset() {
  writeToRegister(CommandReg, MFRC522_SOFTRESET);
}

/**************************************************************************/
/*!

  @brief   Checks the firmware version of the chip.

  @returns The firmware version of the MFRC522 chip.

 */
/**************************************************************************/
byte MFRC522::getFirmwareVersion() {
  byte response;
  response = readFromRegister(VersionReg);
  return response;
}

/**************************************************************************/
/*!

  @brief   Runs the digital self test.

  @returns True if the self test passes, false otherwise.

 */
/**************************************************************************/
boolean MFRC522::digitalSelfTestPass() {
  int i;
  byte n;

  byte selfTestResultV1[] = {0x00, 0xC6, 0x37, 0xD5, 0x32, 0xB7, 0x57, 0x5C,
                          0xC2, 0xD8, 0x7C, 0x4D, 0xD9, 0x70, 0xC7, 0x73,
                          0x10, 0xE6, 0xD2, 0xAA, 0x5E, 0xA1, 0x3E, 0x5A,
                          0x14, 0xAF, 0x30, 0x61, 0xC9, 0x70, 0xDB, 0x2E,
                          0x64, 0x22, 0x72, 0xB5, 0xBD, 0x65, 0xF4, 0xEC,
                          0x22, 0xBC, 0xD3, 0x72, 0x35, 0xCD, 0xAA, 0x41,
                          0x1F, 0xA7, 0xF3, 0x53, 0x14, 0xDE, 0x7E, 0x02,
                          0xD9, 0x0F, 0xB5, 0x5E, 0x25, 0x1D, 0x29, 0x79};
  byte selfTestResultV2[] = {0x00, 0xEB, 0x66, 0xBA, 0x57, 0xBF, 0x23, 0x95,
                          0xD0, 0xE3, 0x0D, 0x3D, 0x27, 0x89, 0x5C, 0xDE,
                          0x9D, 0x3B, 0xA7, 0x00, 0x21, 0x5B, 0x89, 0x82,
                          0x51, 0x3A, 0xEB, 0x02, 0x0C, 0xA5, 0x00, 0x49,
                          0x7C, 0x84, 0x4D, 0xB3, 0xCC, 0xD2, 0x1B, 0x81,
                          0x5D, 0x48, 0x76, 0xD5, 0x71, 0x61, 0x21, 0xA9,
                          0x86, 0x96, 0x83, 0x38, 0xCF, 0x9D, 0x5B, 0x6D,
                          0xDC, 0x15, 0xBA, 0x3E, 0x7D, 0x95, 0x3B, 0x2F};
  byte *selfTestResult;
  switch(getFirmwareVersion()) {
    case 0x91 :
      selfTestResult = selfTestResultV1;
      break;
    case 0x92 :
      selfTestResult = selfTestResultV2;
      break;
    default:
      return false;
  }

  reset();
  writeToRegister(FIFODataReg, 0x00);
  writeToRegister(CommandReg, MFRC522_MEM);
  writeToRegister(AutoTestReg, 0x09);
  writeToRegister(FIFODataReg, 0x00);
  writeToRegister(CommandReg, MFRC522_CALCCRC);

  // Wait for the self test to complete.
  i = 0xFF;
  do {
    n = readFromRegister(DivIrqReg);
    i--;
  } while ((i != 0) && !(n & 0x04));

  for (i=0; i < 64; i++) {
    if (readFromRegister(FIFODataReg) != selfTestResult[i]) {
      Serial.println(i);
      return false;
    }
  }
  return true;
}
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

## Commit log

2020-03-14 get SD card and RFID scanner to work at the same time
    by moving the RFID scanner to the other SPI port
2020-03-15 introduce volume buttons, simplify code for playlist advance
2020-03-15 wip: schematics
    [hardware.kicad_pcb, hardware.sch]
2020-03-17 wip: power supply
    [hardware.sch]
2020-03-18 wip: power switch and cleanup
    [hardware.sch]
2020-03-20 fix power switch circuit
    [hardware.sch]
2020-03-22 added test code for low power microcontroller
2020-03-23 wip: power measurement documentation
2020-03-23 completed power estimation
2020-04-07 update schematics
    [hardware.sch]
2020-04-07 added kicad cache and backup files to gitignore
2020-04-17 update schematics, improve power distribution concept
    [hardware.sch]
2020-04-22 some fixes to the schematics
    [hardware.sch]
2020-04-26 change pin assignment to avoid strapping pins
    [LauraBox.ino]
2020-04-26 fix spin lock for atomic card id exchange
    [LauraBox.ino]
2020-04-26 fix ULP hanging after resume playback
    [LauraBox.ino]
2020-04-26 reset paused flag on resume
    [LauraBox.ino]
2020-04-26 rename NFC SS pin into SDA for consistency
2020-04-26 update schematics for changed pin assignment
    [hardware.sch]
2020-04-26 fix signal names for I2S, and wrong wiring
    [hardware.sch]
2020-05-12 some fixes and add ADC measurement for battery voltage
    [hardware.sch]
2020-05-15 use external library for ESP32-audioI2S, add voice messages to SPIFFS
2020-05-15 some corrections about the voice error
    [LauraBox.ino]
2020-05-19 correction: amplifier has separate pin for enable
    [hardware.sch]
2020-05-24 minor correction
    [hardware.sch]
2020-05-24 Reduce coupling capacitor between DAC and amplifier
    This is necessary to reduce the pop noise when switching on. The corner frequency is still much lower than the bandwidth of the speakers.
    [hardware.sch]
2020-05-24 fix ERC errors, separate AMP_UNMUTE from AMP_ENA
    [hardware.sch]
2020-05-24 fix missing annotation
    [hardware.sch]
2020-05-24 fix name of EXT header
    [hardware.sch]
2020-05-24 layout corrections
    [hardware.sch]
2020-05-24 use POWER_CTRL to shutdown the amp, AMP_ENA to mute it
    [hardware.sch]
2020-05-24 add reset button
    [hardware.sch]
2020-05-24 reduce standby power consumption
2020-06-04 fixed annotation
    [hardware.sch]
2020-06-05 assign footprints, generate netlist
    [hardware.sch]
2020-06-05 fix footprint for choke
    [hardware.kicad_pcb, hardware.sch]
2020-06-11 [wip] board layout
    [hardware.kicad_pcb, hardware.sch]
2020-06-20 [wip] routing...
    [hardware.kicad_pcb, hardware.sch]
2020-06-21 PBC routing complete
    [hardware.kicad_pcb, hardware.sch]
2020-08-30 corrections to PCB, started 3D model
    [Lautsprecher Visaton FRS 5 X - 8 Ohm.SLDPRT, Lautsprecher Visaton FRS 5 X - 8 Ohm.step, hardware.kicad_pcb]
2020-08-31 added 3D models for electronic subcomponents
    [Charger.FCStd, GY-PCM510x.FCStd, RC522 v8.step]
2020-08-31 added 3D model for main board with subcomponents
    [GY-PCM510x.FCStd, Hardware.FCStd]
2020-09-07 finalize 3D model
    [Charger.FCStd, Hardware.FCStd, Lautsprecher Visaton FRS 5 X - 8 Ohm.SLDPRT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]
2020-09-07 finalize PCB
    [hardware.kicad_pcb, hardware.sch]
2020-09-07 create milling files for PCB
    [hardware-B_Cu.gbr, hardware-Edge_Cuts.gbr, hardware-F_Cu.gbr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]
2020-09-19 update 3D model and PCB
    [hardware.kicad_pcb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]
2020-09-25 fix 3D model (wrong material thickness)
2020-10-04 final model update
    [base plate.FCStd]
2020-10-05 intermediate commit
    [base plate.FCStd]
2020-10-10 fix auto-download of audio files
    [LauraBox.ino]
2020-10-10 more fixes for auto download of tracks
    [LauraBox.ino]
2020-10-11 fix not advancing to next track, improve status messages when downloading
    [LauraBox.ino]
2020-10-11 some fixes and improvements
    [LauraBox.ino]
2021-01-04 replace automatic download of playlists in the background by triggered download through magic card ID
    [LauraBox.ino]
2021-01-04 disable button auto-repeat
2021-01-06 add base plate files
    [base plate 40mm.FCStd, base-plate-40mm.stl, base-plate.stl]
2021-01-27 add schematics as SVG
2021-01-27 add title and estimated date
    [hardware.sch]
2021-10-02 fix missing leading zeros in card id
    [LauraBox.ino]
2022-11-13 adjustments: reroute tracks to keep-out antenna add optional pin headers below/close to buttons for external push buttons minor cleanup
    [hardware.kicad_pcb, hardware.kicad_sch]
